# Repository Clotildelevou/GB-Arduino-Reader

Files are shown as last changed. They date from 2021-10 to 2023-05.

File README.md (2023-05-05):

# GB-Arduino-Reader
This is a little PCB connecting an arduino to a GBA cardtrige connector. The final aim of this project is to dump the cartdrige's ROM and enevtually write on the RAM. 

# Progress

**Hardware :**

▰▰▰▰▰▰▰▰▰▰ 100%
> The PCB first version exists and is functionnal. A wild second version may appear !

**Microcontroller's code :**

▰▱▱▱▱▱▱▱▱▱ 10%
> A POC exists and it is actually possible to fetch some code !

**Executor code :**

▰▰▰▰▰▰▰▰▰▱ 90%
> The ROM dumper is ready ! Different types of MBC are not supported yet tho

# Principles

## The Cartdridge

The cartdrige has 32 pins and this is their usage :

| Pin | Name | Description |
|-----|---|---|
| 1 | VCC | +5VDC |
| 2 | PHI | CPU Clock |
| 3 | WR | Write |
| 4 | RD | Read |
| 5 | CS | SRAM select |
| 6 | A0 | Address 0 |
| 7 | A1 | Address 1 |
| 8 | A2 | Address 2 |
| 9 | A3 | Address 3 |
| 10  | A4 | Address 4 |
| 11  | A5 | Address 5 |
| 12  | A6 | Address 6 |
| 13  | A7 | Address 7 |
| 14  | A8 | Address 8 |
| 15  | A9 | Address 9 |
| 16  | A10 | Address 10 |
| 17  | A11 | Address 11 |
| 18  | A12 | Address 12 |
| 19  | A13 | Address 13 |
| 20  | A14 | Address 14 |
| 21  | A15 | Address 15 |
| 22  | D0 | Data 0 |
| 23  | D1 | Data 1 |
| 24  | D2 | Data 2 |
| 25  | D3 | Data 3 |
| 26  | D4 | Data 4 |
| 27  | D5 | Data 5 |
| 28  | D6 | Data 6 |
| 29  | D7 | Data 7 |
| 30  | RST | Reset |
| 31  | AUDIOIN | Used by MP3 player |
| 32  | GND | Ground |

## The Shift Registers

The arduino we use (Arduino Nano V3.X) only has 22 digital pins. Shift registers become handy. Shift registers are often used for the purpose of saving pins on the microcontroller, as every microcontroller has a limited number of I/O pins (GPIO).

### The logic
The 595 has two registers (which can be thought of as “memory containers”), each with just 8 bits of data. The first one is called the Shift Register. The Shift Register lies deep within the IC circuits, quietly accepting input.

Whenever we apply a clock pulse to a 595, two things happen:

The bits in the Shift Register move one step to the left. For example, Bit 7 accepts the value that was previously in bit 6, bit 6 gets the value of bit 5 etc.
Bit 0 in the Shift Register accepts the current value on DATA pin. At the rising edge of the pulse, if the data pin is high, then a 1 gets pushed into the shift register. Otherwise, it is a 0.
On enabling the Latch pin, the contents of Shift Register are copied into the second register, called the Storage/Latch Register. Each bit of the Storage Register is connected to one of the output pins QA–QH of the IC, so in general, when the value in the Storage Register changes, so do the outputs.

Shift Register animation

### Pinout

pinout

**GND** should be connected to the ground of Arduino.

**VCC** is the power supply for 74HC595 shift register which we connect the 5V pin on the Arduino.

**SER** (Serial Input) pin is used to feed data into the shift register a bit at a time.

**SRCLK** (Shift Register Clock) is the clock for the shift register. The 595 is clock-driven on the rising edge. This means that in order to shift bits into the shift register, the clock must be HIGH. And bits are transferred in on the rising edge of the clock.

**RCLK** (Register Clock / Latch) is a very important pin. When driven HIGH, the contents of Shift Register are copied into the Storage/Latch Register; which ultimately shows up at the output. So the latch pin can be seen as like the final step in the process to seeing our results at the output, which in this case are LEDs.

**SRCLR** (Shift Register Clear) pin allows us to reset the entire Shift Register, making all its bits 0, at once. This is a negative logic pin, so to perform this reset; we need to set the SRCLR pin LOW. When no reset is required, this pin should be HIGH.

**OE** (Output Enable) is negative logic too: When the voltage on it is HIGH, the output pins are disabled/set to high impedance state and don’t allow current to flow. When OE gets low voltage, the output pins work normally.

**QA–QH** (Output Enable) are the output pins and should be connected to some type of output like LEDs, 7 Segments etc.

**QH’** Pin outputs bit 7 of the ShiftRegister. It is there so that we may daisychain 595s: if you connect this QH’ to the SER pin of another 595, and give both ICs the same clock signal, they will behave like a single IC with 16 outputs. Of course, this technique is not limited to two ICs – you can daisychain as many as you like, if you have enough power for all of them.

# 3D View
This is currently the result of my work : 
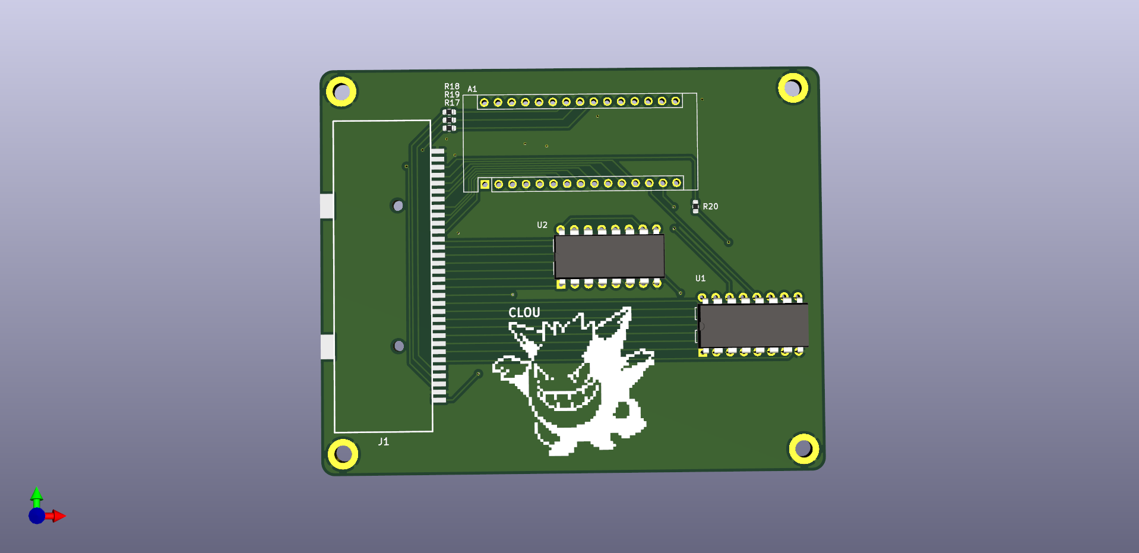
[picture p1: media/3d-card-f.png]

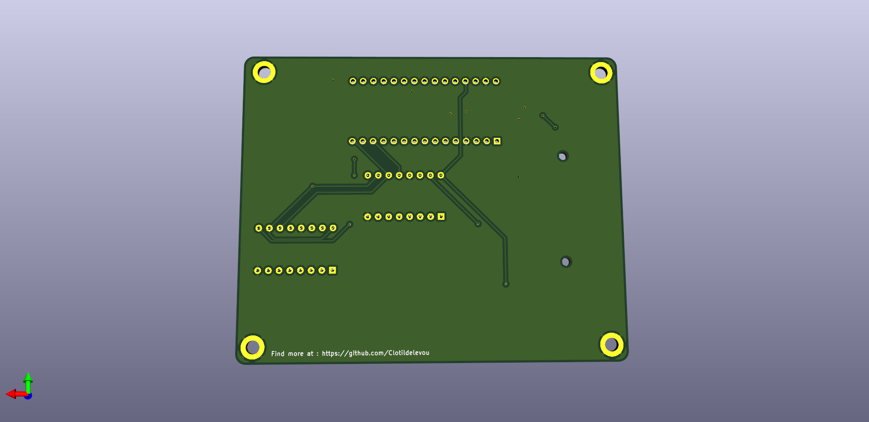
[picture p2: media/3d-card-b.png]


# Gerber view
This is the gerber view :
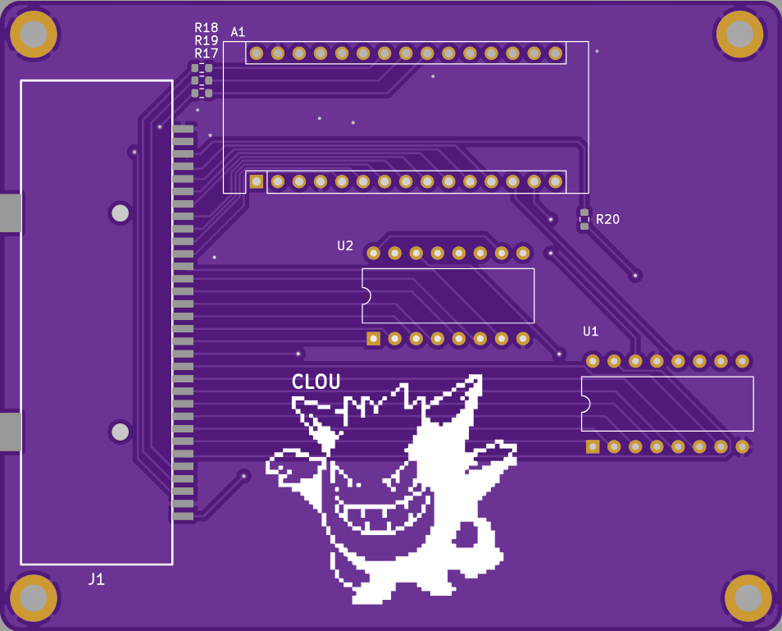
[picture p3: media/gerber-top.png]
TOP

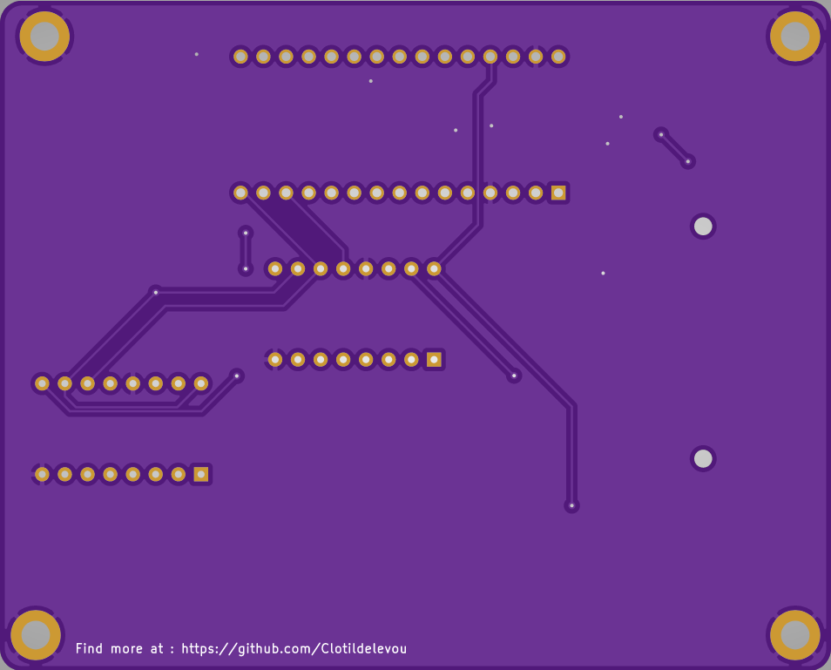
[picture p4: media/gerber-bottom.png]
BOTTOM


# Result

## Pictures
The PCB i got looks like this :
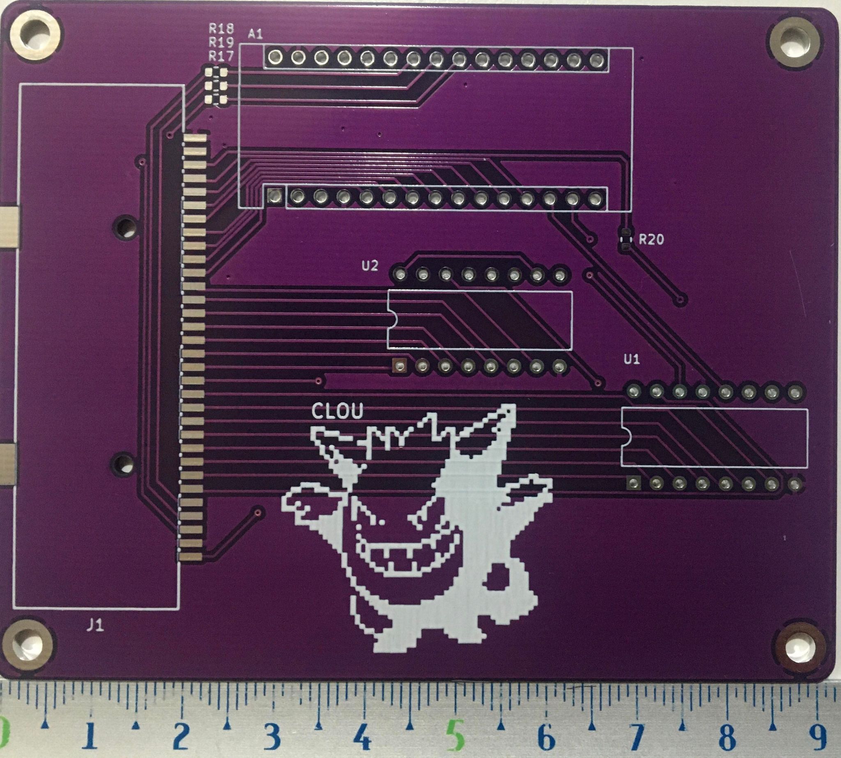
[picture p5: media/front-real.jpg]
FRONT

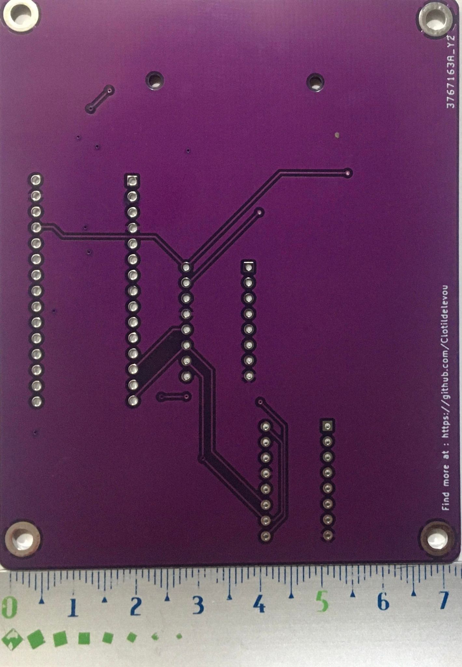
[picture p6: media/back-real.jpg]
BACK

SOLDERED

## Problems on the PCB

I had a little problem on the card. The GBA pads were a bit hidden the pins of the cartdrigde reader. To solve this problem I just removed the little plastic guides (see image below) with a plier and i glued it directly on the PCB. It is quite solid but i'll change the guides position for the next version !

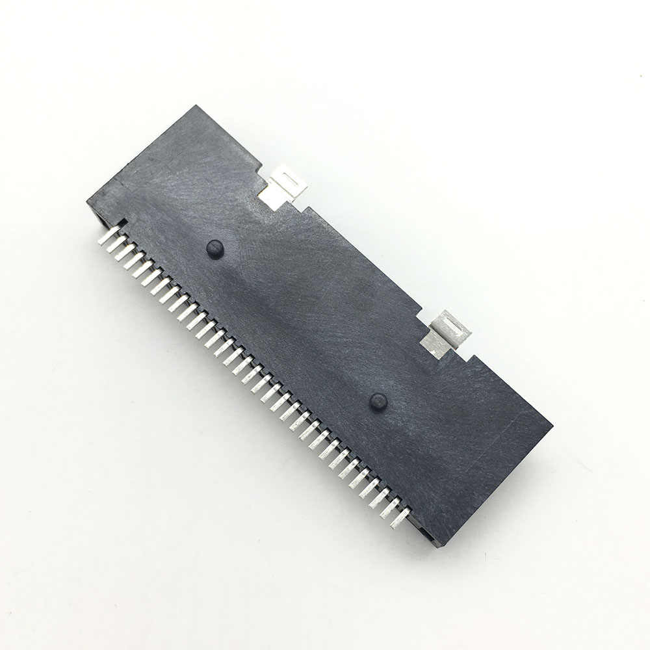
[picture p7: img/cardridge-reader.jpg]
GUIDES


# Sources
[Inside Gadgets](https://www.insidegadgets.com)

[lastminuteengineers](https://lastminuteengineers.com/74hc595-shift-register-arduino-tutorial/)

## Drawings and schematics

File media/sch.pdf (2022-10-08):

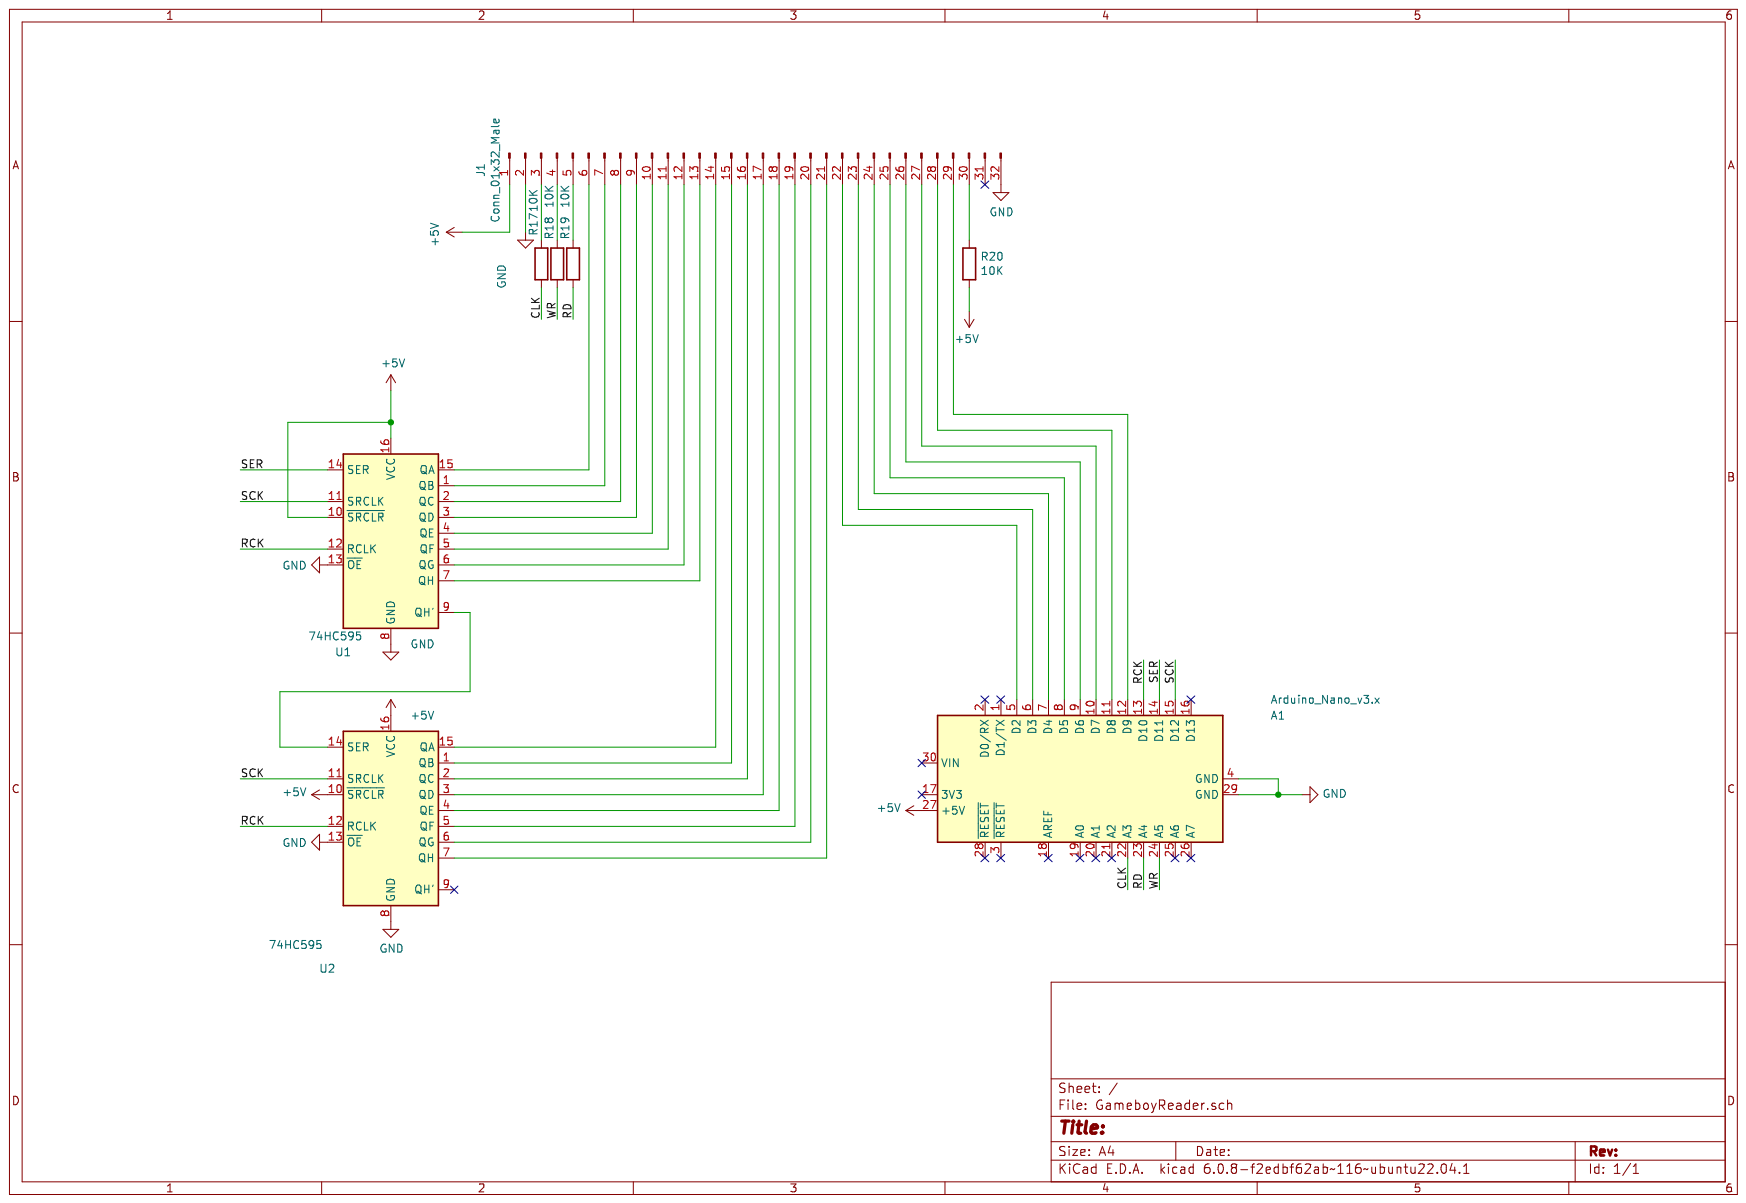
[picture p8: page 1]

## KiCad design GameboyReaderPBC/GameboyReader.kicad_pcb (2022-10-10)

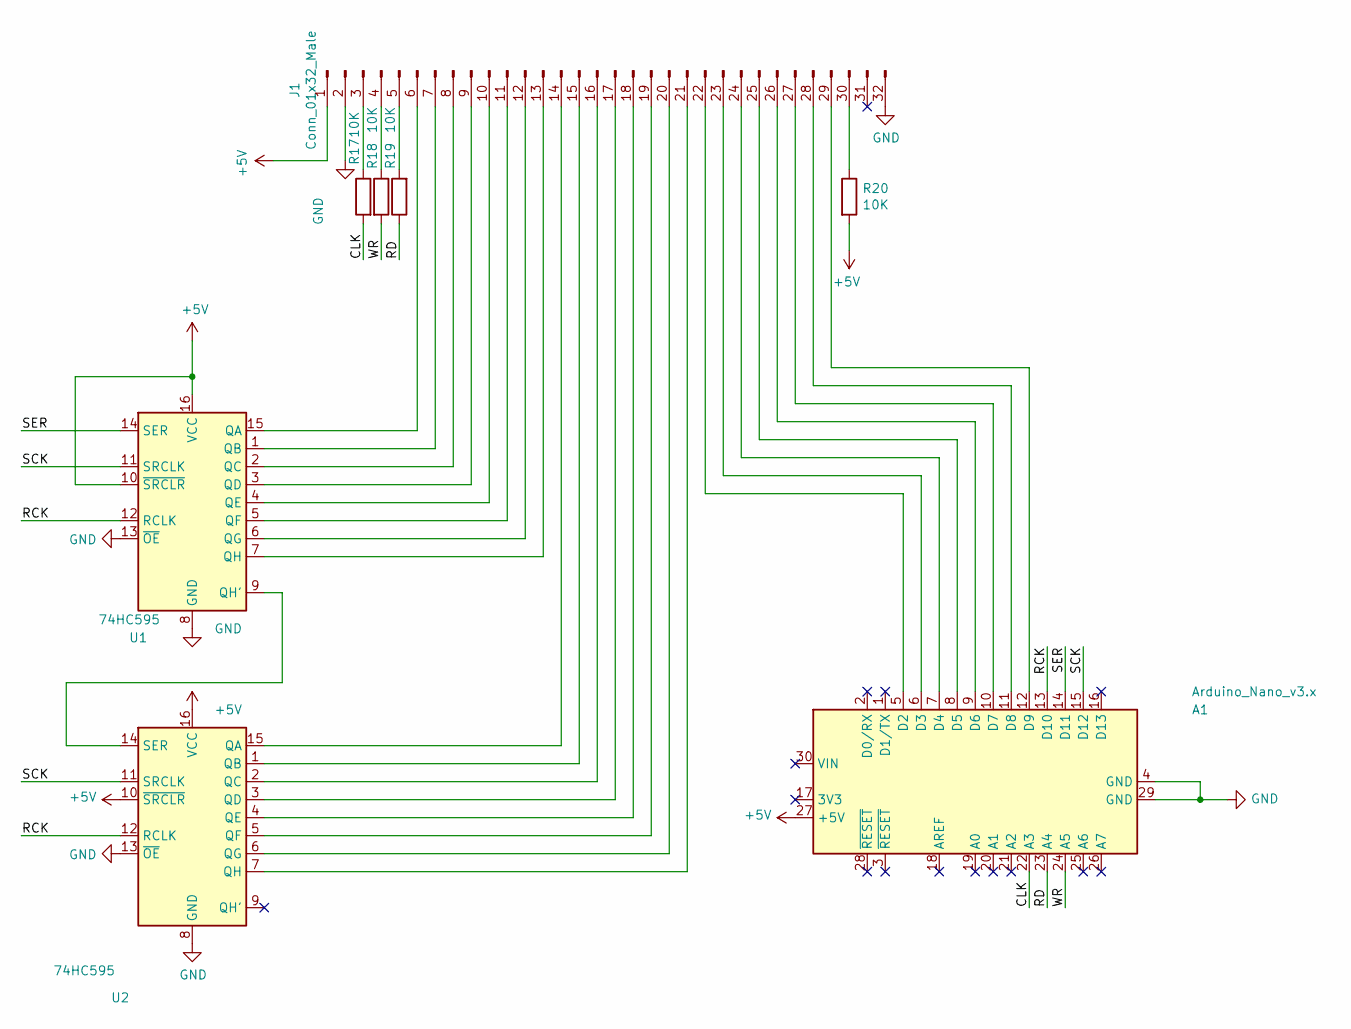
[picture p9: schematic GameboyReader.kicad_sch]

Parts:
A1: Arduino_Nano_v3.x; Arduino_Nano
J1: Conn_01x32_Male; GameboyConnector
R17, R18, R19, R20: 10K; R_0603_1608Metric
U1, U2: 74HC595; DIP-16_W10.16mm

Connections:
+5V: A1.27 (+5V), J1.1, R20.2, U1.10 (~SRCLR), U1.16 (VCC), U2.10 (~SRCLR), U2.16 (VCC)
/CLK: A1.22 (A3), R17.2
/RCK: A1.13 (D10), U1.12 (RCLK), U2.12 (RCLK)
/RD: A1.23 (A4), R19.1
/SCK: A1.15 (D12), U1.11 (SRCLK), U2.11 (SRCLK)
/SER: A1.14 (D11), U1.14 (SER)
/WR: A1.24 (A5), R18.2
GND: A1.4 (GND), A1.29 (GND), J1.2, J1.32, U1.8 (GND), U1.13 (~OE), U2.8 (GND), U2.13 (~OE)
unnamed: A1.5 (D2), J1.22
unnamed: A1.6 (D3), J1.23
unnamed: A1.7 (D4), J1.24
unnamed: A1.8 (D5), J1.25
unnamed: A1.9 (D6), J1.26
unnamed: A1.10 (D7), J1.27
unnamed: A1.11 (D8), J1.28
unnamed: A1.12 (D9), J1.29
unnamed: J1.3, R17.1
unnamed: J1.4, R18.1
unnamed: J1.5, R19.2
unnamed: J1.6, U1.15 (QA)
unnamed: J1.7, U1.1 (QB)
unnamed: J1.8, U1.2 (QC)
unnamed: J1.9, U1.3 (QD)
unnamed: J1.10, U1.4 (QE)
unnamed: J1.11, U1.5 (QF)
unnamed: J1.12, U1.6 (QG)
unnamed: J1.13, U1.7 (QH)
unnamed: J1.14, U2.15 (QA)
unnamed: J1.15, U2.1 (QB)
unnamed: J1.16, U2.2 (QC)
unnamed: J1.17, U2.3 (QD)
unnamed: J1.18, U2.4 (QE)
unnamed: J1.19, U2.5 (QF)
unnamed: J1.20, U2.6 (QG)
unnamed: J1.21, U2.7 (QH)
unnamed: J1.30, R20.1
unnamed: U1.9 (QH'), U2.14 (SER)

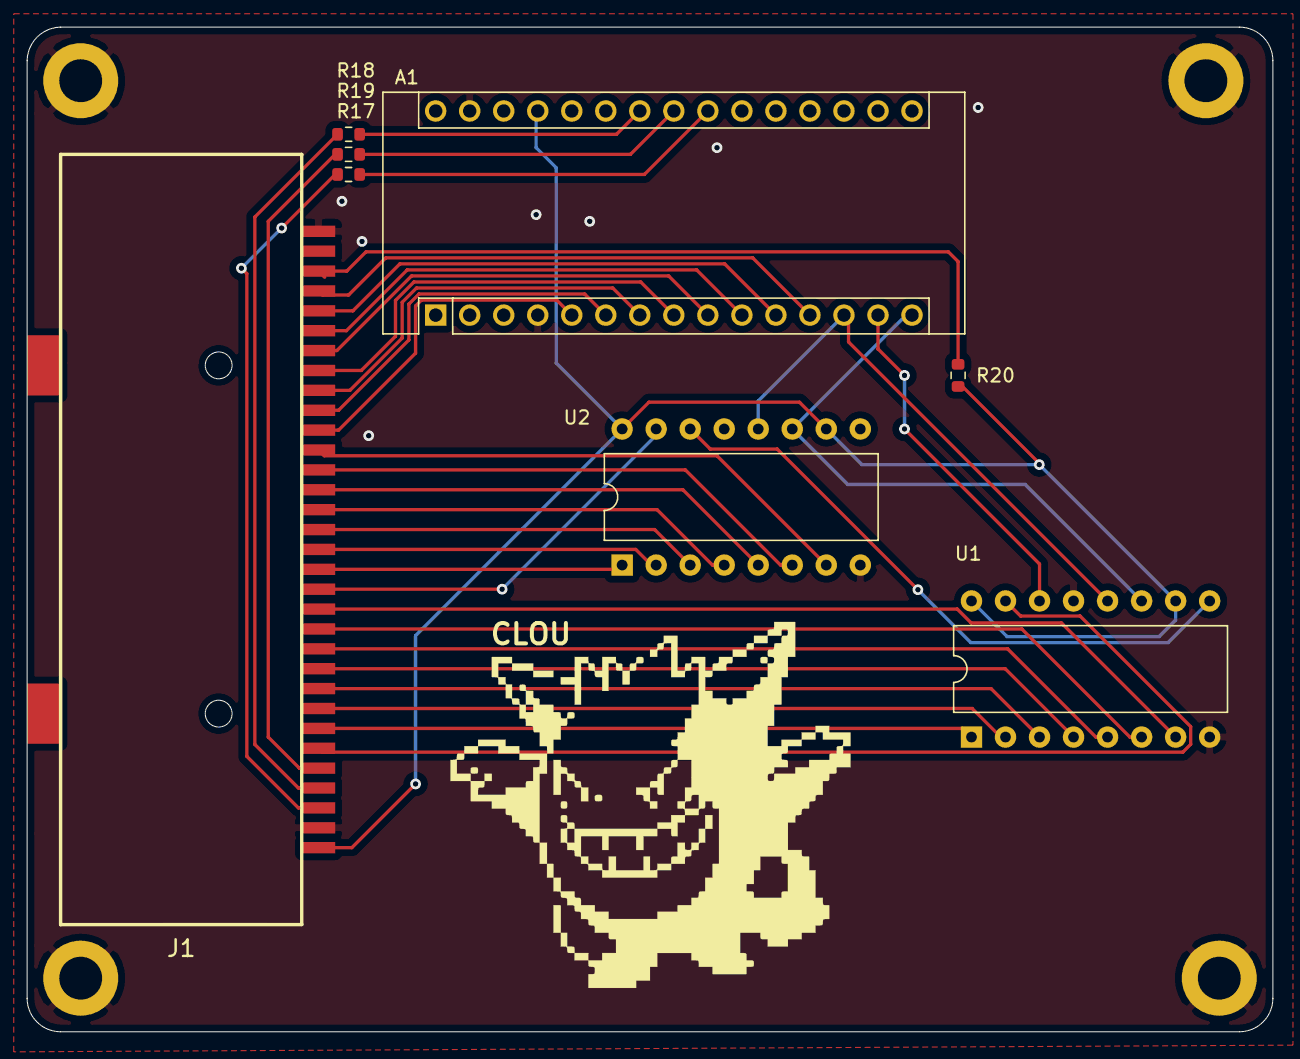
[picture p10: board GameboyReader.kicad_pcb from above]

Board: 2 copper layers, 93.0 x 75.0 mm, 8 parts (0 on the bottom side), 37 nets.

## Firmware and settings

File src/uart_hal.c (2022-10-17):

#include "uart_hal.h"

#define F_CPU 16000000

volatile static uint8_t rx_buf[RX_BUF_SIZE] = {0};
volatile static uint16_t rx_count = 0;


void uart_init(uint32_t baudrate)
{
    baudrate = F_CPU / (16 * baudrate) - 1;
    //Set baudrate
    UBRR0H = (baudrate & 0x0F00) >> 8;
    UBRR0L = baudrate & 0x00FF;

    //Enable TX and RX and interruption
    UCSR0B = (1 << TXEN0) | (1 << RXEN0) | (1 << TXCIE0) | (1 << RXCIE0);
    sei();
}

void uart_send_byte(uint8_t c)
{
    while (!(UCSR0A & (1 << UDRE0)));
    UDR0 = c;
}

void uart_send_buffer(uint8_t *buf, uint16_t len)
{
    for(int i = 0; i < len; i++)
    {
        uart_send_byte(buf[i]);
    }
}

void uart_send_string(uint8_t *str)
{
    while (*str != '\0')
    {
        uart_send_byte(*str);
        str++;
    }
}


ISR(USART_TX_vect)
{

}

uint8_t uart_recv_byte()
{
    while (! (UCSR0A & (1 << RXC0)));
    return UDR0;
}

uint16_t uart_read()
{
    static uint16_t rx_read_pos = 0;
    uint8_t data = 0;

    data = rx_buf[rx_read_pos];
    rx_read_pos++;
    rx_count--;
    if(rx_read_pos >= RX_BUF_SIZE)
        rx_read_pos = 0;
    return data;
}


ISR(USART_RX_vect)
{
    volatile static uint16_t offset = 0;
    rx_buf[offset] =  uart_recv_byte();
    rx_count++;
    offset++;
    if(offset >= RX_BUF_SIZE){
        offset = 0;
    }
}

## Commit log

2021-10-24 [PROJECT] Project done :)
    [GameboyReader.kicad_pcb, GameboyReader.sch]
2021-10-24 [IMG] Gerber view
2021-10-29 [FIX] Regenerated gerbers
    [GameboyReader-B_Cu.gbr, GameboyReader-B_Mask.gbr, GameboyReader-B_Paste.gbr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]
2021-11-17 [REFACTO] dirname
    [GameboyReader-B_Cu.gbr, GameboyReader-B_Mask.gbr, GameboyReader-B_Paste.gbr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]
2021-11-17 [FEAT] Soldered Picture
2021-11-18 [FIX] Print error
2021-11-18 [FIX] string print
2022-10-10 uart: first commit
2022-10-10 kicad: updated versions extensions
    [GameboyReader.kicad_pcb, GameboyReader.kicad_sch]
2022-10-10 uart: uart init
2022-10-12 uart: init with interruptions
2022-10-12 uart: send bytes
2022-10-12 uart: send buffer
2022-10-12 uart: first test
2022-10-12 uart: makefile
2022-10-12 uart fix: baudrate formula
    [uart_hal.c]
2022-10-12 uart fix: interrupts enabled
    [uart_hal.c]
2022-10-12 uart: send string
2022-10-17 uart: interrupt handler moved
2022-10-17 uart: tx functions reordered
2022-10-17 uart: rx interrupt handler
2022-10-17 uart: rx byte
2022-10-17 uart: rx buffer
